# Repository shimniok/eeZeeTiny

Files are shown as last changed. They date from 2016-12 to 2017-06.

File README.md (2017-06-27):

# eeZeeTiny

A breadboard development board for 8-pin ATtiny (13, 85, etc.) including AVR ISP header, reset switch and pull-up resistor, and bypass caps. Perfect for low power projects, dedicated tasks, Internet of Things, and so much more.

[eeZeeTiny User Guide](documentation/)

[Buy now on Tindie](https://www.tindie.com/products/bot_thoughts/eezee-tiny-breakout-programming-board-kit/).

Features
* It doesn't get any smaller than this!
* Designed for breadboarding: all pins exposed, all support circuits included
* Includes AVR ISP header for in-circuit programming
* 0.1uF and 10uF filtering capacitors installed underneath
* Reset switch and pull-up resistor included
* Works with ATtiny11, ATtiny12, ATtiny13, ATtiny25, ATtiny45, ATtiny85
* Program ATtinyX5 with Arduino IDE

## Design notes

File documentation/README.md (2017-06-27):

# eeZeeTiny User Guide

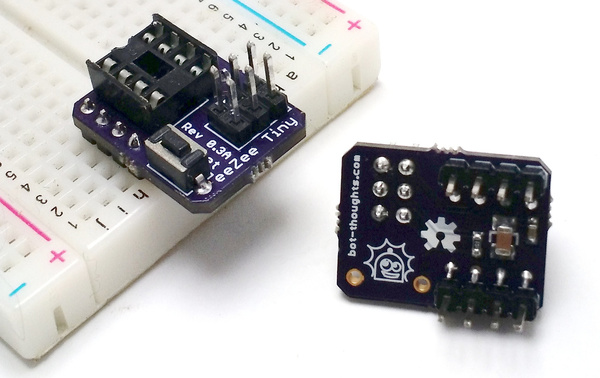
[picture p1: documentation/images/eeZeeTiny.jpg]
eeZeeTiny


## Introduction

The eeZeeTiny is a compact, convenient breadboard development board for 8-pin ATtiny (13, 85, etc.) including AVR ISP header, reset switch and pull-up resistor, and power supply filtering caps. These compact chips are perfect for low power projects, dedicated tasks, Internet of Things, and so much more.

Want one? [Buy now on Tindie](https://www.tindie.com/products/bot_thoughts/attiny85--attiny13-development-board/).

## Pinout

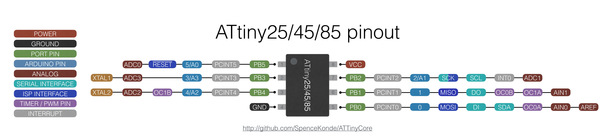
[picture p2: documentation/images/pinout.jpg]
pinout


## Getting Started

Click the links below to help you get started with your eeZeeTiny board.

  * First: [Assembling your board](Assembling.md)
  * Next: [You'll need a hardware programmer](HardwareProgrammer.md)

Now, select which environment to use for development:
  * [Getting started with Arduino](Arduino.md)
  * [Getting started with Atmel Studio](AtmelStudio.md) (Windows only)
  * [Getting started with avr-gcc](AvrGcc.md)

## Reference

### Fuses

* I recommend the convenient [Engbedded Fuse Calculator](http://www.engbedded.com/fusecalc/).

### Operating Conditions

Please use your ATtiny breakout boards with regulated supplies of 5V or less, with minimal ripple, at temperatures around 25C (77F). Do not use the boards in high temperature conditions.

### Default Image

During testing, I flash the *larson scanner* example software onto the chip and then test every pin for connectivity. You can find the code in the ```examples``` directory of this repo.

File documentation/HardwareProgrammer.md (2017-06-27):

# Hardware Programmer

I recommend flashing your boards with [USBasp](http://www.fischl.de/usbasp/). You can buy clones on eBay at a low cost. Other options I have tried will not work out of the box with Arduino, Atmel Studio, and avrdude.

**Atmel Dragon**: For Atmel Studio or avr-gcc, I've found the [AVR Dragon](http://www.atmel.com/tools/avrdragon.aspx) to be a good out-of-the-box solution that includes debugging.

**USBasp and Atmel Studio**: See this article for setting up Atmel Studio to use USBasp. [[pdf](http://mysinski.wieik.pk.edu.pl/MPUandMCU/Installing%20USBasp%20in%20Atmel%20Studio%20ver%207.pdf)]

## ISP Header Pinout

The following is the standard AVR ISP pinout used on eeZeeTiny boards:

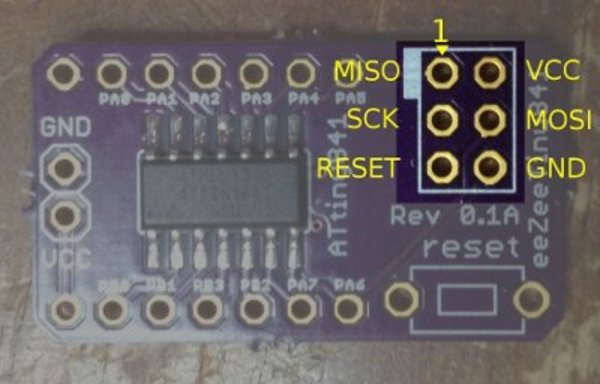
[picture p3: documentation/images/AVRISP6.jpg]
AVRISP Header


The small, white rectangle next to the ISP header marks pin 1.

[Return to README](README.md)

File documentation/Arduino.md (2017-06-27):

# Arduino

Arduino is probably the simplest development environment for developing with your eeZeeTiny board. It incorporates an Integrated Development Environment, toolchain, and software to flash the chip.

The following ATtiny microcontrollers are supported by Arduino with ATTinyCore:
* ATtiny25/45/85
* ATtiny24/44/84
* ATtiny441/841
* ATtiny2313/4313

You will also need a [Hardware Programmer](HardwareProgrammer.md).

You can find example code in the [Arduino examples](../examples/arduino) folder.

1. Download and install the Arduino IDE, version 1.6.* (You should only have to do this once after installing Arduino).
* Next, open the [Boards Manager](https://learn.adafruit.com/add-boards-arduino-v164) and install Spence Konde's [ATTinyCore](https://github.com/SpenceKonde/arduino-tiny-841)
* Select a board from the ```ATTiny Universal``` section of the ```Tools > Boards``` menu:
  * eeZeeTiny: select ```ATtiny25/45/85```
  * eeZeeMedTiny: select ```ATtiny24/44/84```
  * eeZeeTiny841: select ```ATtiny441/841```
  * eeZeeBigTiny: select ```ATtiny2313/4313```
* From the ```Tools``` menu select the chip that is installed on the board.
* Select the appropriate clock frequency:
  * No external crystal? Choose an ```(internal)``` option.
  * External crystal? Select an ```(external)``` frequency option matching your crystal. The eeZee boards ship with 8, 12, 14.7456, 16, or 20 MHz crystals.
* Programmer:
  * Select a programmer labeled ```(ATtiny)``` from ```Tools > Programmers``` corresponding to the hardware programmer you're using (See *Hardware Programmer*).

You should now be able to write your code and flash the chip.

[Return to README](README.md)

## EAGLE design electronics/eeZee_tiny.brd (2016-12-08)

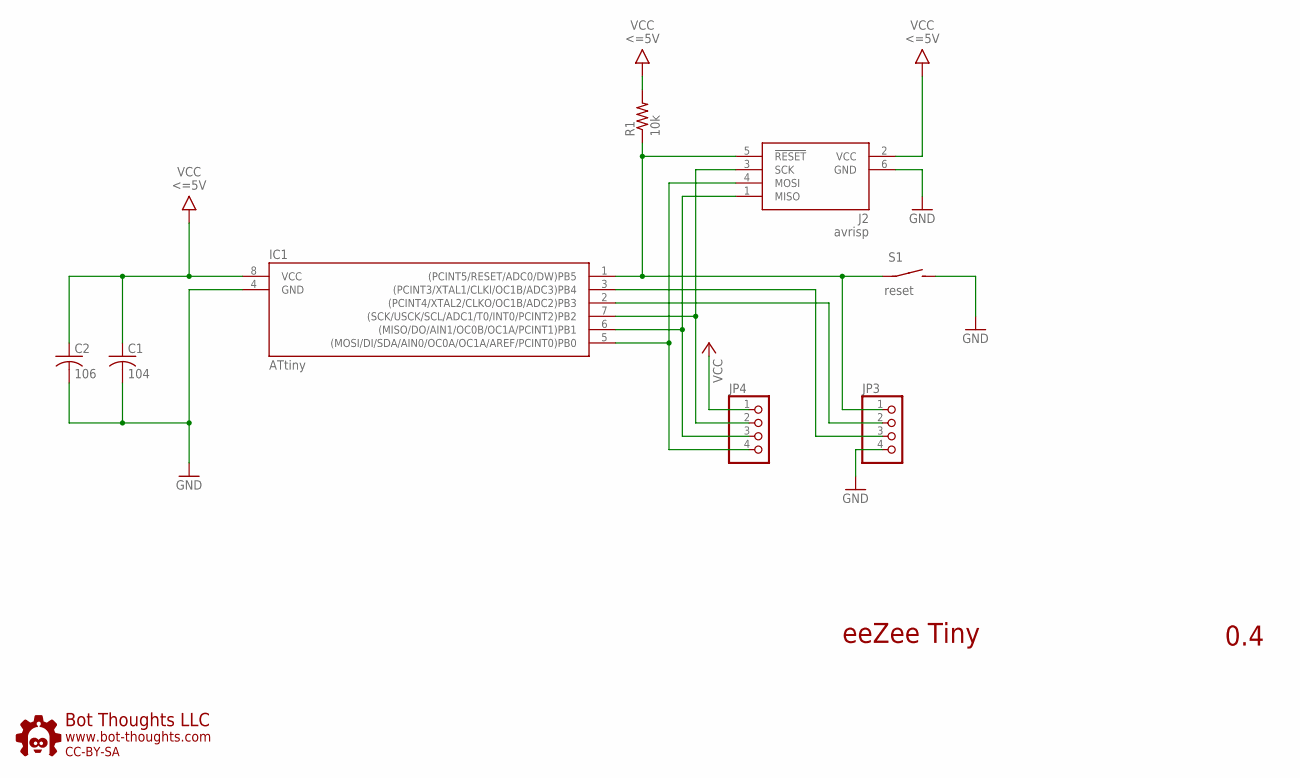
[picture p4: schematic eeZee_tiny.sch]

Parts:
C1: 104; C0603; PARTNO 0603YC104KAT2A
C2: 106; C1206; PARTNO F930J107MBA
IC1: ATtiny; DIL08
J2: avrisp; CON6P2R
JP3, JP4: PINHD-1X04_2.54-S; 1X04-S
R1: 10k; R0603; PARTNO ERJ-3GEYJ103V
S1: reset; 6MMTACTILE_RECT
U$1: BTLOGO-LOGO-MD; BTLOGOM

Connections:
!RESET: IC1.1 ((PCINT5/RESET/ADC0/DW)PB5), J2.5 (!RESET), JP3.1, R1.1, S1.P$1
GND: C1.2, C2.2, IC1.4 (GND), J2.6 (GND), JP3.4, S1.P$2 (S)
MISO: IC1.6 ((MISO/DO/AIN1/OC0B/OC1A/PCINT1)PB1), J2.1 (MISO), JP4.3
MOSI: IC1.5 ((MOSI/DI/SDA/AIN0/OC0A/OC1A/AREF/PCINT0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), J2.4 (MOSI), JP4.4
PB3: IC1.2 ((PCINT4/XTAL2/CLKO/OC1B/ADC2)PB3), JP3.2
PB4: IC1.3 ((PCINT3/XTAL1/CLKI/OC1B/ADC3)PB4), JP3.3
SCK: IC1.7 ((SCK/USCK/SCL/ADC1/T0/INT0/PCINT2)PB2), J2.3 (SCK), JP4.2
VCC: C1.1, C2.1, IC1.8 (VCC), J2.2 (VCC), JP4.1, R1.2

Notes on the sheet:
eeZee Tiny
0.4

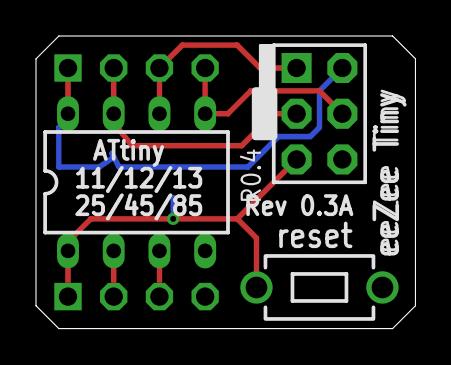
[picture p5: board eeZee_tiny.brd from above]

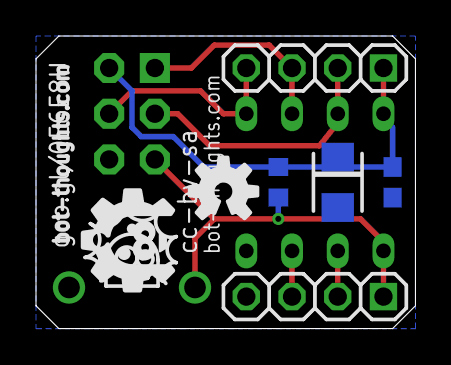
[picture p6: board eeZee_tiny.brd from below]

Board: 2 copper layers, 21.1 x 16.3 mm, 9 parts (6 on the bottom side), 8 nets.

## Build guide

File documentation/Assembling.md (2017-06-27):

# Assembling Your Board

Assembly is easy. And, you can learn how to solder at the same time. Review [Sparkfun's Soldering Tutorial](https://learn.sparkfun.com/tutorials/how-to-solder---through-hole-soldering) if you need to. Here's a helpful info-graphic from the tutorial:

soldering infographic

### You'll need
* Soldering iron, 40W
* Sponge to clean the iron (I recommend a brass sponge)
* Workbench with plenty of light
* Ventilation since breathing flux fumes is irritating
* Soldering surface (e.g., marble tile sample)
* Rosin core solder 0.022” or 0.032” diameter
* Kester #2331-ZX flux pen (optional)

### DIP Socket

* Insert the DIP socket into the board

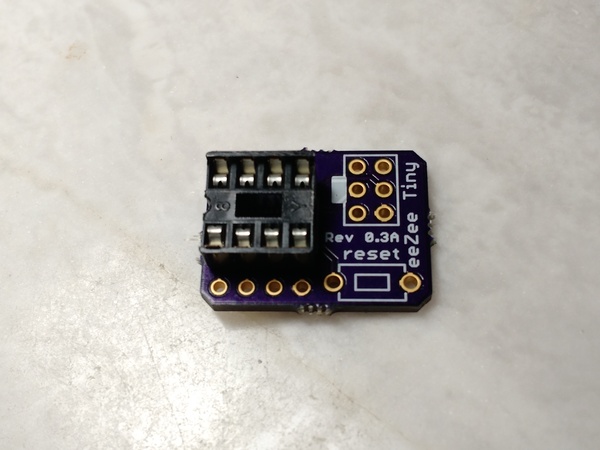
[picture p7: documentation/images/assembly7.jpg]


* Turn the board and socket upside-down and solder in place.
* If you prefer, bend the tabs outward to help hold the socket in place.

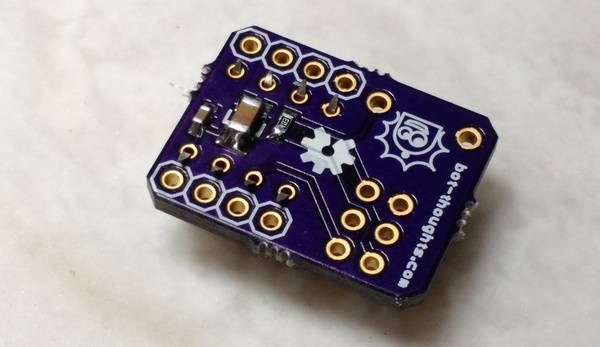
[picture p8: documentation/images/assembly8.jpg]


### Pin Headers

* Insert the pin headers into the breadboard with four empty rows between them.

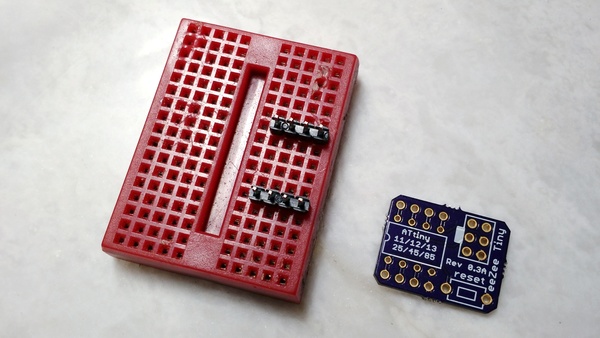
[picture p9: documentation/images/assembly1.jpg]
assembly1


* Place the board on top of the pin headers. MCU side up.
* Hold board down while soldering one pin in each rows

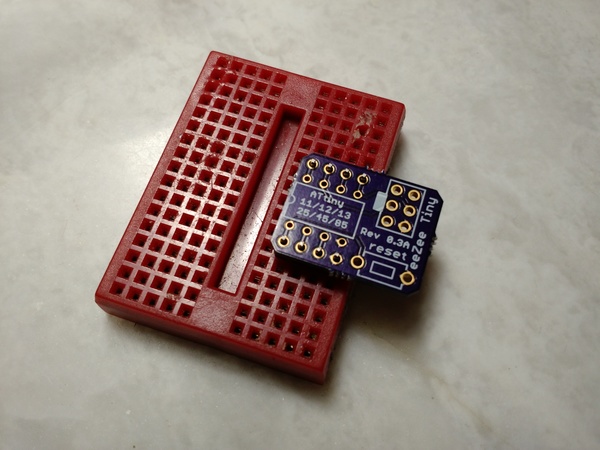
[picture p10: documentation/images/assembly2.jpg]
assembly2


* Solder the remaining pin headers in place.

### AVR ISP Header

* Insert the 2x3 AVR ISP header into the breadboard, short pins up.

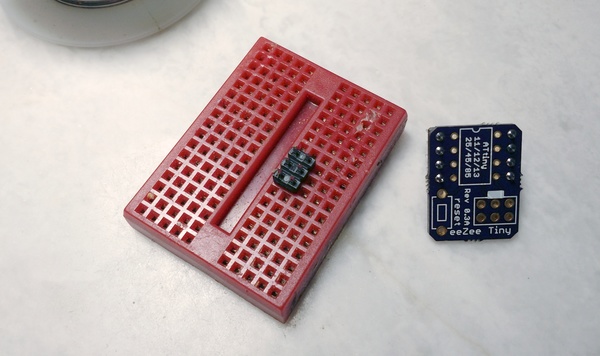
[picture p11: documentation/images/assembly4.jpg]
assembly4


* Place the board onto the 2x3 header
* Holding the board in place, solder one pin.

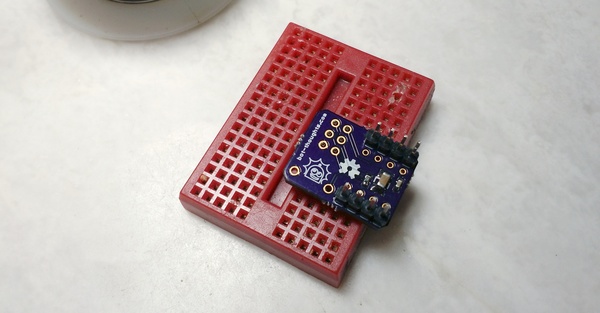
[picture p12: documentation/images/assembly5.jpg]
assembly5


* Check vertical alignment of the ISP header and adjust by melting the solder joint, if necessary.
* Solder the remaining 5 pins.

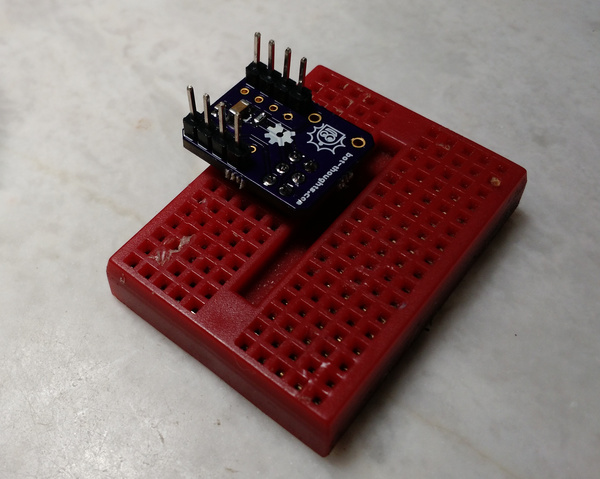
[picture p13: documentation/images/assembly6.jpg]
assembly6


### Reset Switch

* Insert the board into the breadboard right side up.
* Install the switch and bend the pins if necessary to hold it in place.

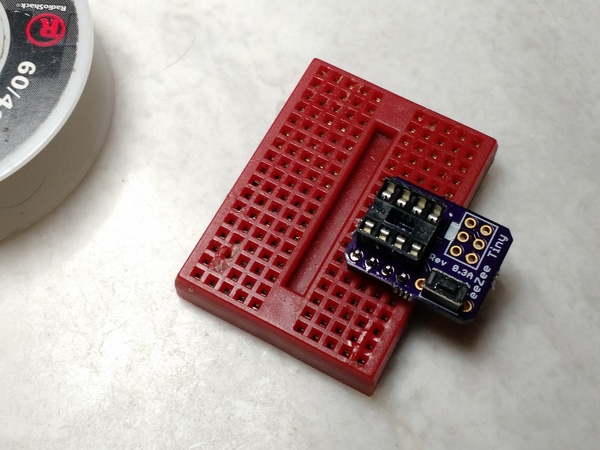
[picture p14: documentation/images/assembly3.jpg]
assembly3


* Solder the switch from the top
* Remove the board and solder the pins from the bottom

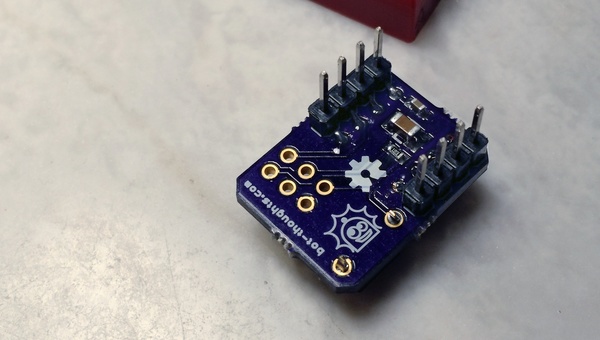
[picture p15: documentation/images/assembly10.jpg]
assembly3


### Cleanup

You'll want to remove the rosin and flux

I usually just use isopropyl alcohol and an old toothbrush

You can also buy chemicals specifically for removing flux and rosin

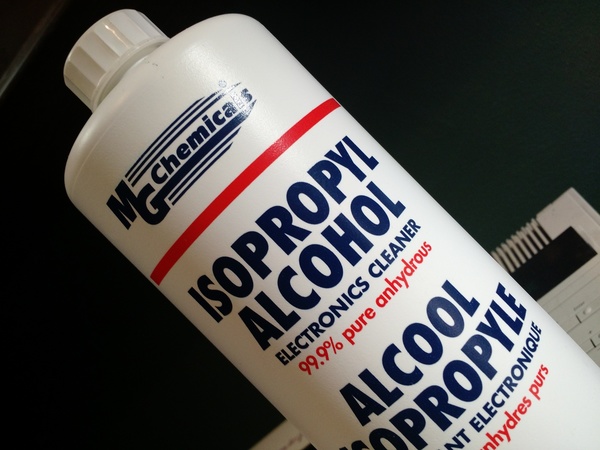
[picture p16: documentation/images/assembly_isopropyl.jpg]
insert pin headers


[Return to README](README.md)

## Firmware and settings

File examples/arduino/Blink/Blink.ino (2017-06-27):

/*
  Blink - example for eeZeeTiny (ATtiny25/45/85)

  Flashes an LED connected to LEDPIN: on for 1 second, off for 1 second.
  
  NOTE: You'll need to connect an LED and resistor to the LEDPIN below.
  Connect LED Anode to LEDPIN. Connect the LED Cathode to a 330 ohm 
  resistor. Connect the other end of the resistor to ground.
 
  This example code is in the public domain.
 */

#define LEDPIN 0  // Arduino pin 0 (ATtiny85 pin PB0)

void setup() {                
  // initialize the digital pin as an output.
  pinMode(LEDPIN, OUTPUT);     
}

void loop() {
  digitalWrite(LEDPIN, HIGH);   // set the LED on
  delay(200);              // wait for a second
  digitalWrite(LEDPIN, LOW);    // set the LED off
  delay(200);              // wait for a second
}

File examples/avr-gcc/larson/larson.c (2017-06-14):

/** ATtiny841 test
 *
 * Author: Michael Shimniok (www.bot-thoughts.com)
 * Description: Sequentially turns on one pin at a time, back and forth
 *   like a Cylon or like Knight Rider from Glenn A. Larson TV shows.)
 *   Skip the RESET pin. For example, with 5 pins, we start at pin 0,
 *   then 1, 2, 3, 4, 3, 2, 1, 0, 1, ... forever.
 */
#include <avr/io.h>
#include <avr/interrupt.h>
#include <util/delay.h>

#define DELAY 300

/*
 * Define a sequence of PORTB pins to turn on one at a time.
 */
#define MAX_PINS 5
uint8_t pins[MAX_PINS] = { PB0, PB1, PB2, PB3, PB4 };

int main()
{
  int i;

  /*
   * Portable, but not efficient, we enable each of the pins as output.
   */
  for (i = 0; i < MAX_PINS; i++) {
    DDRB |= (1<<pins[i]);
  }

  /*
   * Now we loop turning on the pins, back and forth, forever
   */
  while (1) {

    /* We start at pin 0, and stop at the 2nd-to-last pin */
    for (i = 0; i < MAX_PINS-1; i++) {
      PORTB = (1 << pins[i]);
      _delay_ms(DELAY);
    }

    /* We continue with the last pin, and stop at the 0th */
    for (i = MAX_PINS-1; i > 0; i--) {
      PORTB = (1 << pins[i]);
      _delay_ms(DELAY);
    }

  }

}

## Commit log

2012-11-22 Initial revision
    [eeZee_tiny.brd, eeZee_tiny.sch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]
2013-01-08 Moved caps, mods to routing, added logos, added SCK indicator mark
    [eeZee_tiny.brd, eeZee_tiny.sch]
2013-01-31 Revised layout to reduce leading edge and side edge clearances for better breadboarding.
    [eeZee_tiny.brd, eeZee_tiny.sch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]
2013-02-12 Revised board layout removing leading edge, using 6x3mm switch and making board narrower. Revised 8-pin tiny pad thickness minimum. Moved reset resistor for easier assembly. Revised and relocated log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
    [eeZee_tiny.brd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]
2013-08-06 Rev 0.2, shrunk board, mitered corners, added polarity silk to tantalum.
    [eeZee_tiny.brd, eeZee_tiny.sch]
2014-03-31 Converted project to AVR Studio 4, sick of trying to learn gcc assembly when examples are so scarce :)
2014-10-17 Updated DRC with 10mil/8mil spacing, 10mil distances.
    [eeZee_tiny.brd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]
2015-07-30 Added assembly guides
2015-07-31 Renamed assembly guide
2016-12-08 revised 8pdip pads, rerouted avrisp traces, changed passives layout, changed main cap from 100u to 10u and changed to 1206 pkg, replaced attiny13 with attiny25 from bt library, changed avrisp to vers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
    [eeZee_tiny.brd, eeZee_tiny.sch]
2016-12-08 updated gerbers
    [eeZee_tiny.drills.xln]
2017-06-27 added assembly instructions in markdown
2017-06-27 added arduino instructions
2017-06-27 added arduino example

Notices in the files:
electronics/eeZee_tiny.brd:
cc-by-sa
